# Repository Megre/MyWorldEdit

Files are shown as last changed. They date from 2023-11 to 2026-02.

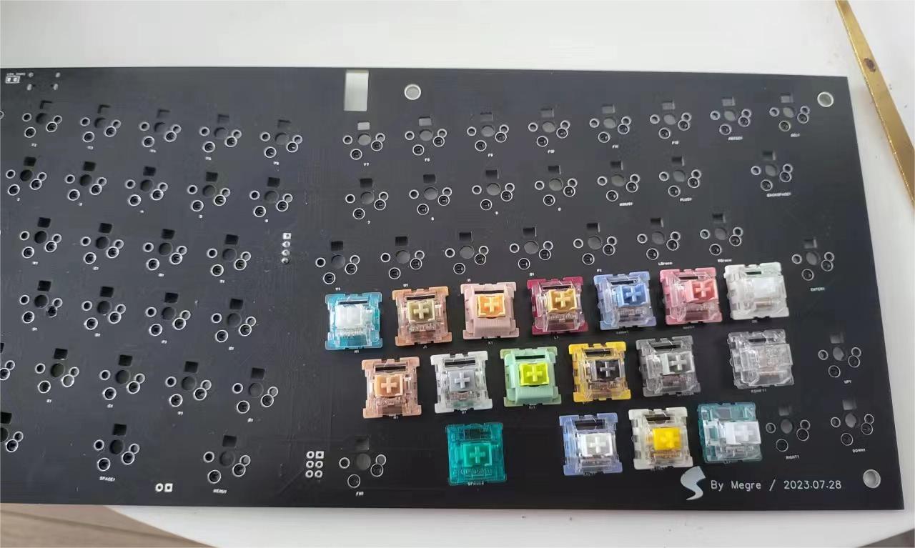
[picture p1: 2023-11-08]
Screenshots/微信图片_20231105111333.jpg

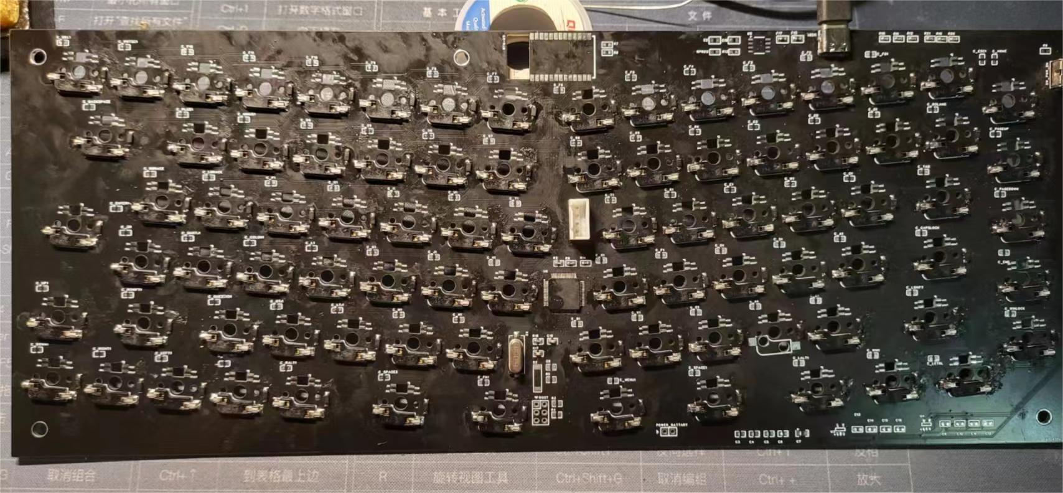
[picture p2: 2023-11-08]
Screenshots/微信图片_20231105111318.jpg

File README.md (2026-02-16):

# MyWorldEdit

Forked from: [WorldEdit](https://github.com/firestaradmin/WorldEdit-No.1)

微信图片_20231018185901

微信图片_20231105111314

## 主要特点

按照个人习惯，使用了欧式大回车。保留了PageUp、PageDown、Home、End、F01-12、方向键等，可用于程序编码及调试。空格使用了两个2.25u按键，实际使用感受正常，没有局促感。右Shift在大回车情况下保留了惯用位置，影响了方向键原有的“山”字布局，变为倒“L”。实际使用需要适应。主要特点：

- USB、蓝牙双模；

- 分裂布局， 欧式大回车；

- 高特青柠轴（五脚轴，支持热插拔）；
- 使用钢珠缩短了键程（1.5mm触发键程），声音小；
- RGB灯效。

与原项目的不同：

- 重新设计了键列，按键数、按键排布均不同；

- 去掉Logo等效，按键灯效改为RGB灯珠。键盘正常使用中，RGB驱动代码有待完善；

- 键盘尺寸不同，宽度约为普通笔记本键盘宽度（具体尺寸可查看外壳3D模型），主要考虑办公桌布局的紧凑。

## 外观

定位板粘贴的是梵高的《星夜》局部，手动裁剪镂空的（也可用喷绘贴纸，需要设计图纸给商家制作）。

上盖板是透明的。为了表现完整的图案，可采用透明键帽+按键文字喷绘粘贴。

图示键帽为Eva初号机。

## 内部结构

内部结构简易设计，从底向上依次为：

外壳，电路板，定位板，键轴，键帽，透明上盖板

- 外壳、定位板、透明上盖板均设计了3D模型。

- Eva初号机XDA键帽一套。由于使用了两个2.25u空格，这套键帽不够用。提供了2.25u键帽的3D模型，可自行打印（光固化打印细腻一些）。也可购买散装2.25u键帽（XDA，15元）。

- 简便起见外壳使用Eva图案和纸封边。

机械键盘素来讲求敲击手感和声音。这套简易设计，完全依靠电路板和定位板缓冲敲击，实际上也有一定的弹性（其他比较有名的结构如Gasket）。声音上，不求动听；反而在键轴内加入钢珠，缩短了键程（大概是选用轴的最短触发键程，实在受不了长键程的机械轴），追求输入简洁明快，有剪刀脚按键的直爽。

追求精致的可以自行设计，3D打印各种结构件进行喷涂、组装。

## BOM

BOM套个娃，参考原BOM，不同如下：

- [高特青柠轴V2](https://s.click.taobao.com/t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)（90颗75元）

- [凯华热插拔轴座](https://s.click.taobao.com/t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)（100个60元）

- [Eva初号机XDA键帽](https://s.click.taobao.com/t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)（35元）

- [蓝牙模块](https://item.taobao.com/item.htm?spm=a1z10.3-c.w4002-3762557689.9.30383217tBDbVX&id=543840346810)（XM-04-HID-K，26元。原BOM型号找不到，实测可用）

- [直径1.3mm钢珠](https://s.click.taobao.com/t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)（改键程用。每个键轴需要2个，用[开轴器](https://s.click.taobao.com/t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)开轴）

- [Eva初号机和纸](https://s.click.taobao.com/t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)（13元）

- 外壳可交商家3D打印（80元）

- 定位板为亚克力板（平面开洞，20元）

- 上盖板为PVC透明板（平面开洞，40元）

- 电路板嘉立创制作（5块板130元）

电子元件参考电路图（eprj文件）。

## 组合键

FN+

- F6: USB/Bluetooth mode
- F7: VolumeDown
- F8: VolumeUp
- F9: Mute
- F10: PlayORPause
- F11: Stop

Menu+

- ScrollLock: Logo LED switch
- Delete: Delete Connect Info
- Insert: Pair Mode
- Home: Bluetooth Reset
- End: Bluetooth Sleep
- F12: LED Flash
- F11: LED Breath
- F3: LED Mode3
- F2: LED Mode2, wasd
- F1: LED Mode1, all
- +: LED Brightness+
- -: LED Brightness-
- Esc: LED turn off

## DIY Tips

可参考[知乎上一篇帖子](https://zhuanlan.zhihu.com/p/116182565)，客制化关键步骤：

- [设计键盘配列](http://www.keyboard-layout-editor.com/)
- 使用该配列[生成定位板](http://builder.swillkb.com/)（DXF文件）
- PCB电路板设计
- 使用该配列[生成固件](https://kbfirmware.com/)（QMK固件），或自行编写固件

通俗的理解是，`键盘配列`给出了你想要的键盘布局，包括每个按键的位置，每个按键的尺寸等。

根据`键盘配列`生成的`DXF文件` 给出了每个键轴的放置位置，也就是`定位板`。由于键轴要穿过`定位板`的开孔插在PCB电路板上，设计PCB时也需要该`DXF文件`，因为定位板的开孔与PCB的`轴座`位置是一一对应的。

使用配列生成[QMK固件](https://qmk.fm/zh-cn/)的步骤不是必须的，也可以自行编写固件。[QMK](https://qmk.fm/zh-cn/)是一个开源项目，[支持STM32和若干非STM32主控](https://docs.qmk.fm/#/platformdev_selecting_arm_mcu)。使用工具自动生成QMK固件需要用到`键盘配列`，用于生成键盘行列的连接（主控识别按键通常基于行列扫描）。

### 键盘配列

设计你的按键排布。



设计输出可表示为文本形式的“Raw Data”，供后续步骤使用：

```
[{r:5,rx:8.75,ry:0.75,x:-7.25},"Esc","F1","F2","F3","F4","F5","F6"],
[{y:-0.5,x:-8.25},"Home"],
[{y:-0.5,x:-7.25},"~\n`","!\n1","@\n2","#\n3","$\n4","%\n5","^\n6"],
[{y:-0.5,x:-8.25},"Page\n\n\n\n\n\nUp"],
[{y:-0.5,x:-7.25,w:1.5},"Tab","Q","W","E","R","T"],
[{y:-0.5,x:-8.25},"Page\n\n\n\n\n\nDown"],
[{y:-0.5,x:-7.25,w:1.75},"Caps Lock","A","S","D","F","G"],
[{y:-0.5,x:-8.25},"End"],
[{y:-0.5,x:-7.25,w:2.25},"Shift","Z","X","C","V","B"],
[{y:-0.5,x:-8.25},"Win\n\n\n\n\n\nLock"],
[{y:-0.5,x:-7.25,w:1.25},"Ctrl",{w:1.25},"Win",{w:1.25},"Alt",{a:7,w:2.25},"",{a:4},"Menu"],
[{r:-5,rx:8.5,x:0.25},"F7","F8","F9","F10","F11","F12","PrtSc\nNmLk","Delete\nInsert"],
[{x:0.25},"&\n7","*\n8","(\n9",")\n0","_\n-","+\n=",{w:2},"Backspace"],
[{x:-0.25},"Y","U","I","O","P","{\n[","}\n]",{x:0.25,w:1.25,h:2,w2:1.5,h2:1,x2:-0.25},"Enter"],
["H","J","K","L",":\n;","\"\n'","|\n\\"],
[{x:0.5},"N","M","<\n,",">\n.","?\n/",{w:1.75},"Shift","↑"],
["Fn",{a:7,w:2.25},"",{a:4},"Alt","Ctrl","←","→","↓"]
```

### 定位板

这里使用的Switch Type是 `MX {_t: 1}`。不同Switch Type会影响开洞的尺寸和形状。



### PCB电路板

嘉立创还是不错的，找元件、设计、打板一体化（也有贴片和3D打印等服务）。

注意，从电路设计就要注意按键轴座的设计了。通常有支持热插拔和非热插拔两种。热插拔轴座需要贴在电路板上，会增加键盘的厚度。非热插拔方式，键轴直接焊接在电路板上。

**不同厂家的轴（如高特、佳达隆、凯华等）通常不兼容**，特别是矮轴等特殊轴，不仅轴插座不兼容，键帽也不兼容（有十字、猪鼻子等）。这就意味着，如果想使用某种轴，**定位板、PCB轴座，从设计之初就应该确定**，找好配套。

### 固件

行列的硬件连接如下图，与PCB设计对应。



基于原项目固件，按硬件连接做了对应改动。

在线配置生成QMK固件似乎也是可行方案。不建议新手使用这种方式。新手的主要问题是，各种细节的疏忽会导致DIY失败。围绕原项目或本项目进行微调，成功概率大。网络上公开的项目较多，但资源不完整，难以判断是否可用，难以学习和复现。至少这两个项目是证实可用的。

# HID Code

| Esc | F1 | F2 | F3 | F4 | F5 | F6 | F7 | F8 | F9 | F10 | F11 | F12 | PrtSc | ScrollLock | PauseBreak |
| --- | ----- | ---- | ----- | ----- | ---- | ---- | ----- | ---- | ----- | ----- | --- | ----- | --- | --- | --- |
| 0x29 | 0x3A  | 0x3B | 0x3C  | 0x3D  | 0x3E | 0x3F | 0x40  | 0x41 | 0x42  | 0x43  | 0x44 | 0x45  | 0x46 | 0x47 | 0x48 |
| | | | | | | | | | | | | | | | |
| ~ | ! | @ | # | $ | % | ^ | & | * | ( | ) | - | + | BackSpace | Insert | Home |
| 0x35 | 0x1E  | 0x1F | 0x20  | 0x21  | 0x22 | 0x23 | 0x24  | 0x25 | 0x26  | 0x27  | 0x2D | 0x2E  | 0x2A | 0x49 | 0x4A |
| | | | | | | | | | | | | | | | |
| Tab | Q | W | E | R | T | Y | U | I | O | P | { | } | \| | Delete | End |
| 0x2B | 0x14  | 0x1A | 0x08  | 0x15  | 0x17 | 0x1C | 0x18  | 0x0C | 0x12  | 0x13  | 0x2F | 0x30  | 0x31 | 0x4C | 0x4D |
| | | | | | | | | | | | | | | | |
| CapsLock | A | S | D | F | G | H | J | K | L | ; | ' | Enter | | | PageUp |
| 0x39 | 0x04  | 0x16 | 0x07  | 0x09  | 0x0A | 0x0B | 0x0D  | 0x0E | 0x0F  | 0x33  | 0x34 | 0x28  | 0x00 | 0x00 | 0x4B |
| | | | | | | | | | | | | | | | |
| LShift | Z | X | C | V | B | N | M | , | . | / | RShift | Up | | | PageDown |
| xxCK | 0x1D  | 0x1B | 0x06  | 0x19  | 0x05 | 0x11 | 0x10  | 0x36 | 0x37  | 0x38  | xxCK | 0x52  | 0x00 | 0x00 | 0x4E |
| | | | | | | | | | | | | | | | |
| LCtrl | Win | LAlt | Space | RAlt  | FN | Menu | RCtrl | Left | Down  | Right | | | | | |
| xxCK | xxCK  | xxCK | 0x2C  | xxCK  | xxSK | xxSK | xxCK  | 0x50 | 0x51  | 0x4F  | 0x00 | 0x00  | 0x00 | 0x00 | 0x00 |
| | | | | | | | | | | | | | | | |
| Sleep | LCtrl | Win  | LAlt  | Space | Menu | FN | Space | RAlt | RCtrl | Left  | Right  | Down  | | | |
| 0x82 | xxCK  | xxCK | xxCK  | 0x2C  | xxSK | xxSK | 0x2C  | xxCK | xxCK  | 0x50  | 0x4F | 0x51  | | | |

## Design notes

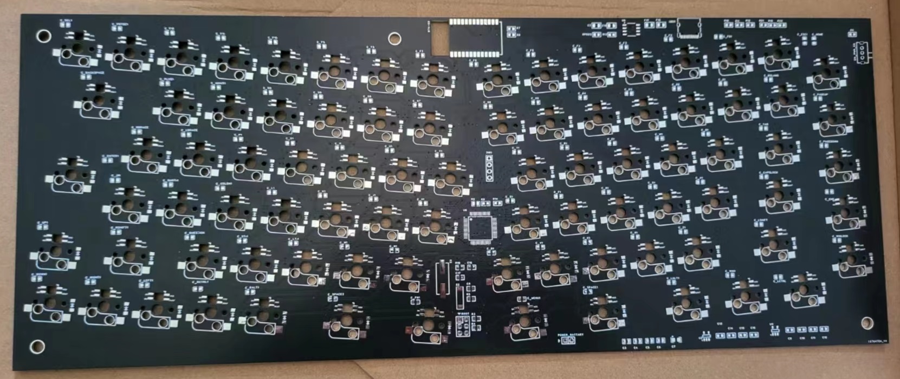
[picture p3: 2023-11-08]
Screenshots/微信图片_20231105111319.jpg

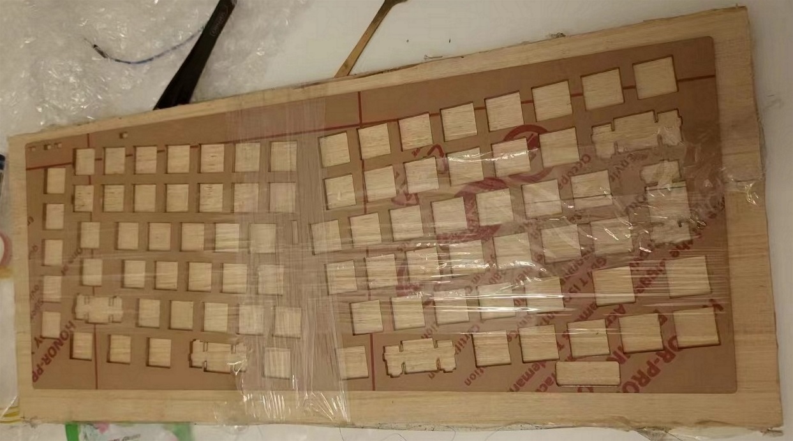
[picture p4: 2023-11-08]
Screenshots/微信图片_20231105111332.jpg

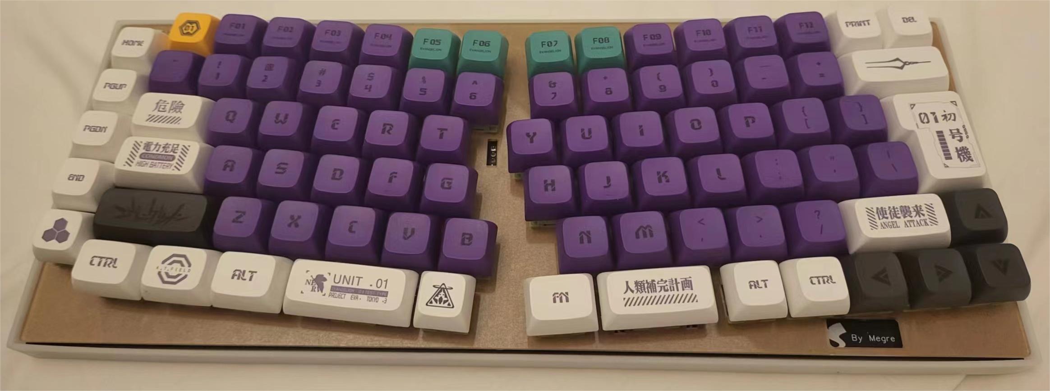
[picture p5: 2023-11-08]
Screenshots/微信图片_20231105111327.jpg

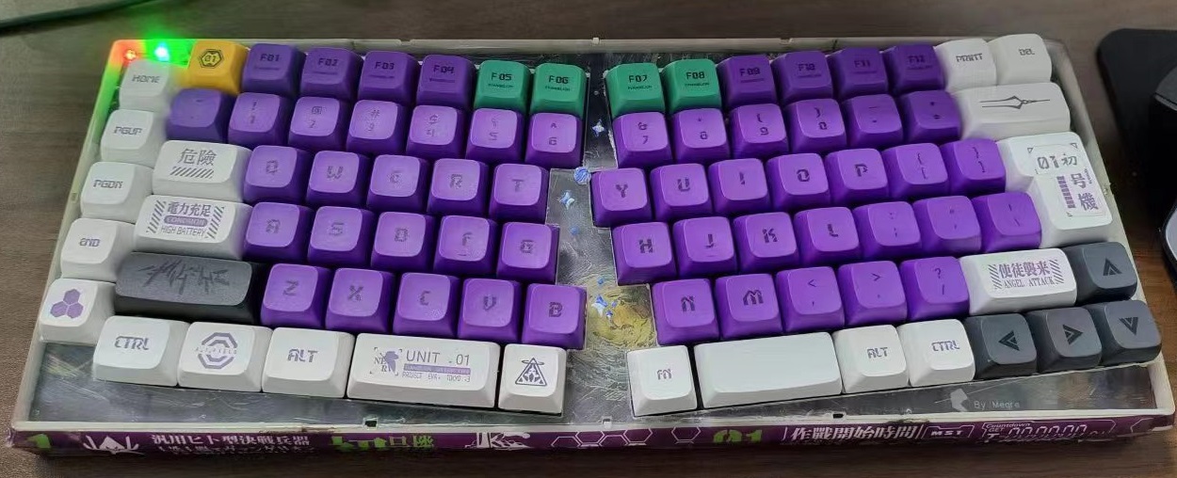
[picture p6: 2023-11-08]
Screenshots/微信图片_20231105111314.jpg

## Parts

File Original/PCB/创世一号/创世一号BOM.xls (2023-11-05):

Comment | Description | Designator | Footprint | LibRef | Quantity
HDR2x3 | Connector | BOOT | PIN-2x3-2.54-1.0 | HDR2x3 | 1
BTK-05-blueteeth |  | BTK-05 | BTK-05-bluteeth | BTK-05-blueteeth | 1
22pF | Capacitor | C1, C2 | RC0603 | CAP1 | 2
104 | Capacitor | C3, C4, C5, C6, C8 | RC0603 | CAP1 | 5
10uf | Tantalum Capacitor | C7 | CAP0805 | CAP-TANTALUM | 1
105 | Capacitor | C9, C12, C13, C16 | 0603 | CAP | 4
22nf | Capacitor | C10, C14 | 0603 | CAP | 2
104 | Capacitor | C11, C15 | 0603 | CAP | 2
10uf | Capacitor | C18, C19 | 0805 | CAP | 2
LED | LED | CAPS_LED, LED1, LED2, LED3, LED4, LED5, LED6, LED7, LED8, LED_CHRG, PWR, STATE_LED | LED-0805 | LED | 12
Diode |  | D2, D3, D4, D5, D6, D7, D8, D9, D10, D11, D12, D13, D14, D15, D16, D17, D18, D19, D20, D21, D22, D23, D24, D25, D26, D27, D28, D29, D30, D31, D32, D33, D34, D35, D36, D37, D38, D39, D40, D41, D42, D43, D44, D45, D46, D47, D48, D49, D50, D51, D52, D53, D54, D55, D56, D57, D58, D59, D60, D61, D62, D63, D64, D66, D67, D68, D69, D70, D71, D72, D73, D74, D75, D76, D77, D78, D82, D83, D84, D85, D86, D87, D88, D89, D90, D91, D92 | SDO-123 | Diode | 87
500mA | Resistor | F1 | 0805 | Res2 | 1
MX_SW | with Fixation pins 1-Pole w/LED | KEY_0, KEY_1, KEY_2, KEY_3, KEY_4, KEY_5, KEY_6, KEY_7, KEY_8, KEY_9, KEY_-, KEY_", KEY_/, KEY_;, KEY_[, KEY_\, KEY_], KEY_`, KEY_<, KEY_=, KEY_>, KEY_A, KEY_Alt, KEY_Alt2, KEY_B, KEY_Backspace, KEY_C, KEY_CapsLock, KEY_Ctrl, KEY_Ctrl2, KEY_D, KEY_Delete, KEY_Down, KEY_E, KEY_End, KEY_Enter, KEY_ESC, KEY_F, KEY_F1, KEY_F2, KEY_F3, KEY_F4, KEY_F5, KEY_F6, KEY_F7, KEY_F8, KEY_F9, KEY_F10, KEY_F11, KEY_F12, KEY_FN, KEY_G, KEY_H, KEY_Home, KEY_I, KEY_Insert, KEY_J, KEY_K, KEY_L, KEY_Left, KEY_M, KEY_Menu, KEY_N, KEY_O, KEY_P, KEY_PageDown, KEY_PageUp, KEY_Pause, KEY_PrtSc, KEY_Q, KEY_R, KEY_Right, KEY_S, KEY_ScrollLock, KEY_Shift, KEY_Shift2, KEY_Space, KEY_T, KEY_Tab, KEY_U, KEY_Up, KEY_V, KEY_W, KEY_Win, KEY_X, KEY_Y, KEY_Z | MX_SW-5 | MX_SW-5 | 87
HDR1x3 | Connector | LEDPwrCON | PIN-3-2.54-1.0 | HDR1x3 | 1
HDR1x2 | Connector | Power | PIN-2-2.54-1.0 | HDR1x2 | 1
NPN | NPN Bipolar Transistor | Q1 | S8050-TO-92 | NPN | 1
1M |  | R1 | RC0603 | R | 1
0R |  | R2 | RC0603 | R | 1
10K |  | R3, R4, R5 | RC0603 | R | 3
1k | Resistor, [NoValue] | R6, R7, R9, R13, R15, | 0603 | RES, R, Res2 | 5
1.5K | Resistor | R10 | 0603 | Res2 | 1
22R | Resistor | R11, R12,R17 | 0603 | Res2 | 3
10k | Resistor | R16 | 0603 | Res2 | 1
2k | Resistor | RPROG | 0603 | RES | 1
SW-SPST | Single-Pole, Single-Throw Switch | S1 | SMT-KEY | SW-SPST | 1
SWITCH-SPST | Switch | SW_PWR | Switch_3p_2.5mmjianju | SWITCH-SPST | 1
HDR1x4 | Connector | SWD | PIN-4-2.54-1.0 | HDR1x4 | 1
STM32F103RCT6 | MCU | U1 | QFP-64-0.5 | STM32F103RxTx | 1
HT16K33 SOP-28 |  | U2 | HT16K33-28PIN-SOP28 | HT16K33 SOP-28 | 1
RT9193 |  | U3, U4 | SOT-23-5 | RT9193 | 2
TP4056 |  | U5 | ESOP8 | TP4056 | 1
USB Slave_c | USB Connector | USB | MICRO USB CONNECTOR TYPEB-ST-MC-5F-01 | MICRO USB CONNECTOR TYPEB | 1
8M | Crystal Oscillator | X1 | HC49-SMD | XTAL_SMD | 1
名称 | 描述 | 封装 | 数量
HDR2x3 | Connector | PIN-2x3-2.54-1.0 | 1
BTK-05-blueteeth | 蓝牙HID模块 | BTK-05-bluteeth | 1
22pF | Capacitor | RC0603 | 2
104 | Capacitor | RC0603 | 5
10uf | Tantalum Capacitor | CAP0805 | 1
105 | Capacitor | 0603 | 4
22nf | Capacitor | 0603 | 2
104 | Capacitor | 0603 | 2
10uf | Capacitor | 0805 | 2
LED | LED | LED-0805 | 12
Diode | 二极管 | SDO-123 | 87
500mA | 限流保险管 | 0805 | 1
MX_SW | 键盘轴体 | MX_SW-5 | 87
HDR1x3 | Connector | PIN-3-2.54-1.0 | 1
HDR1x2 | Connector | PIN-2-2.54-1.0 | 1
NPN | NPN Bipolar Transistor | S8050-TO-92 | 1
1M |  | RC0603 | 1
0R |  | RC0603 | 1
10K |  | RC0603 | 3
1k | Resistor, [NoValue] | 0603 | 5
1.5K | Resistor | 0603 | 1
22R | Resistor | 0603 | 3
10k | Resistor | 0603 | 1
2k | Resistor | 0603 | 1
SW-SPST | 按键 | SMT-KEY | 1
SWITCH-SPST | 开关 | Switch_3p_2.5mmjianju | 1
HDR1x4 | Connector | PIN-4-2.54-1.0 | 1
STM32F103RCT6 | MCU主控 | QFP-64-0.5 | 1
HT16K33 SOP-28 | 灯控 | HT16K33-28PIN-SOP28 | 1
RT9193 | 稳压 | SOT-23-5 | 2
TP4056 | 电源管理 | ESOP8 | 1
USB Slave_c | MicroUSB母座 | MICRO USB CONNECTOR TYPEB-ST-MC-5F-01 | 1
8M | 晶振 | HC49-SMD | 1

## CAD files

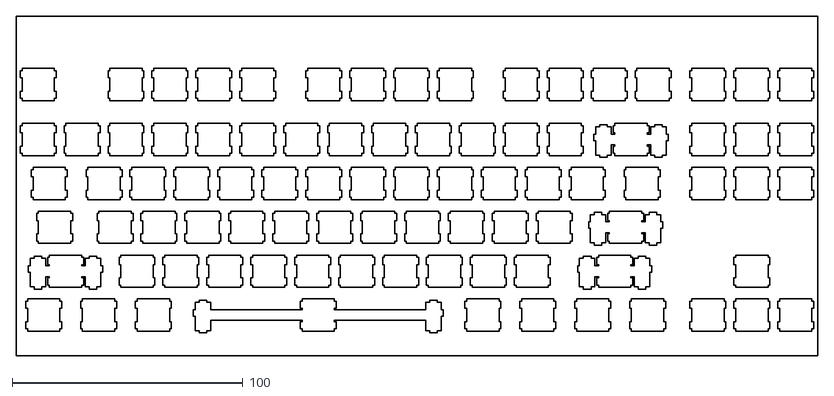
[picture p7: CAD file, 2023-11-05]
Original/LayOut/87layout.dxf
347.7 x 147.1

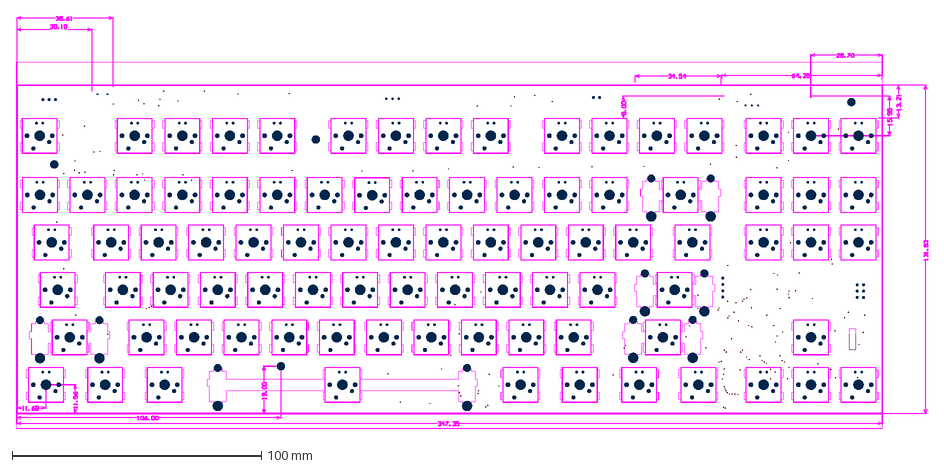
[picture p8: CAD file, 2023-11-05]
Original/PCB/创世一号/创世一号pcb.DXF
366.0 x 165.4 mm

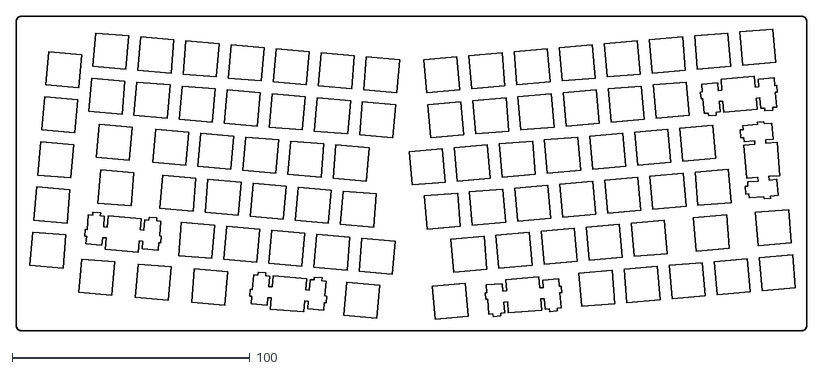
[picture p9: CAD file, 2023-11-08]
PCB/my plate case.dxf
332.5 x 132.2

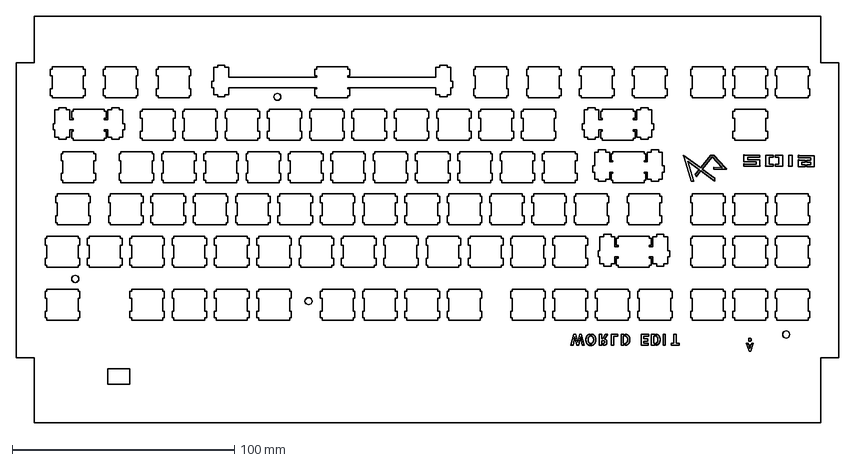
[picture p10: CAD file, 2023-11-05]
Original/SolidWorks外壳/平板型式 - 键盘钣金.DXF
370.1 x 183.2 mm

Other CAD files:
3D/2.25u.3dm
3D/上盖-亚克力.3dm
3D/上盖-内嵌.3dm
3D/上盖.3dm
3D/开关手柄.3dm

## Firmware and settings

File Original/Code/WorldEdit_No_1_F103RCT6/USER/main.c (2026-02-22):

#include "main.h"
#include "deepSleep.h"

void TIM3_CH3_PWM_init(u16 arr,u16 psc);
void myUSB_Init(void);
void sysInit(void);

static unsigned short sleepTime1SCounter = 0;
static uint32_t usbConfigStableTime = 0;
unsigned char sleepTime50MsCounter = 0;
unsigned char LED_breath_Flag = 0;
unsigned char LED_LOGOBreath_Flag = 0;
unsigned char LED_LOGOENBreath_Flag = 0;
unsigned char system_Status = 1;  	// 1:运行中，0：休眠中
unsigned char g_Flag = 0;
uint8_t ledLogoPWM = 80;
int8_t ledLogoPWMDelt = 0;
bool g_USBModeFlag = FALSE;
bool g_startUSBConfigStableTimer = FALSE;
static uint32_t g_sleepTimeout = 27; // 秒

int main()
{
	sysInit();	
	BTK05_Wake();	
	Turn_On_State_LEDs(1);

	while(1)
	{ 
		if(g_USBModeFlag) //USB模式下 
		{
			if(sleepTime1SCounter <= 1000)
			{
				myKeyBoard_ScanKeyAndUpdataATBuffer();//键盘事件更新
				if(g_myKeyBoard_DataWaitForUploadFlag == 1)
				{
					sleepTime1SCounter = 0;
					g_myKeyBoard_DataWaitForUploadFlag = 0;
					if(bDeviceState == CONFIGURED)//如果连接上了 USB
						Keyboard_Send(BTK05_ATKeyDataPack+4);
					//GPIO_SetBits(LED_LOGO_GPIOPort,LED_LOGO_GPIOPin);
				}
				
				Try_Switch_to_BLUETEETH_Mode();
				continue;
			}
			
			if(system_Status == 0)
			{
				myKeyBoard_ScanKeyAndUpdataATBuffer();//键盘事件更新
				if(g_myKeyBoard_DataWaitForUploadFlag == 1)
				{
					g_myKeyBoard_DataWaitForUploadFlag = 0;
					if(bDeviceState == CONFIGURED)//如果连接上了 USB
						Keyboard_Send(BTK05_ATKeyDataPack+4);
					//GPIO_SetBits(LED_LOGO_GPIOPort,LED_LOGO_GPIOPin);
					system_Status = 1;
					TIM_Cmd(TIM2, ENABLE);  //使能TIMx	
					sleepTime1SCounter = 0;
					if(LED_Status)	
						LED_WakeUp();	
				}
				continue;
			}
			
			if(sleepTime1SCounter > 1000)
			{
				TIM_Cmd(TIM2, DISABLE);  //失能TIMx		
				system_Status = 0;
				LED_GoToSleep();
			}
		}
		else//蓝牙模块模式
		{
			// 一段时间后没有按下任何按键，则进入休眠状态
			if(sleepTime1SCounter >= g_sleepTimeout && BTK05_Status == BTK_WAKE)   
			{				
				//进入休眠模式...
				BTK05_Sleep();           // 休眠BTK05
				TIM_Cmd(TIM2, DISABLE);  // 失能TIMx		
				system_Status = 0;
				LED_ESCOFF();	 
				
				// 让 MCU 休眠, 进入STOP模式
				Enter_Deep_Sleep();	  
    
				// 唤醒后执行
				BTK05_Wake();
				TIM_Cmd(TIM2, ENABLE);
				system_Status = 1;  		// 恢复工作状态
				sleepTime1SCounter = 0; // 清除休眠计时
			}
			//如果键盘处于醒着的状态
			else if(sleepTime1SCounter < g_sleepTimeout && BTK05_Status == BTK_WAKE)
			{
				myKeyBoard_ScanKeyAndUpdataATBuffer();//键盘事件更新
				if(g_myKeyBoard_DataWaitForUploadFlag == 1)
				{
					g_myKeyBoard_DataWaitForUploadFlag = 0;
					//GPIO_ResetBits(LED_LOGO_GPIOPort,LED_LOGO_GPIOPin);
					BTK05_UART_SendKeyData(BTK05_ATKeyDataPack,12);
					sleepTime1SCounter = 0;

//					if(ATKeyControlByte5 != 0) 
//					{
//						GPIO_SetBits(LED_LOGO_GPIOPort,LED_LOGO_GPIOPin);
//					}
//					else
//					{
//						GPIO_ResetBits(LED_LOGO_GPIOPort,LED_LOGO_GPIOPin);
//					}
				}
			}
			//如果蓝牙处于休眠状态
			else if(BTK05_Status == BTK_SLEEP)
			{
				myKeyBoard_ScanKeyAndUpdataATBuffer();
				if(g_myKeyBoard_DataWaitForUploadFlag == 1)
				{
					system_Status = 1;
					BTK05_Wake();//唤醒BTK05
					TIM_Cmd(TIM2, ENABLE);  //使能TIMx	
					sleepTime1SCounter = 0;
					g_myKeyBoard_DataWaitForUploadFlag = 0;
					if(LED_Status)	
						LED_WakeUp();
					BTK05_UART_SendKeyData(BTK05_ATKeyDataPack,12);
				}
			}
			
			Try_Switch_to_USB_Mode();
			
		}
		
//		if(LED_BreathEfectFlag && LED_breath_Flag)
//		{
//			LED_BreathProcess();
//			LED_breath_Flag = 0;
//		}
//		if(LED_LOGOBreath_Flag  && LED_LOGOENBreath_Flag)//logo呼吸灯处理标志
//		{
//			TIM_SetCompare3(TIM3, ledLogoPWM);
//			if(ledLogoPWMDelt == 0)
//			{
//				ledLogoPWM --;
//				if(ledLogoPWM <= 30)
//					ledLogoPWMDelt = 1;
//			}
//			else
//			{
//				ledLogoPWM ++;
//				if(ledLogoPWM == 98)
//					ledLogoPWMDelt = 0;
//			}
//			LED_LOGOBreath_Flag = 0;

//		}
	}
}

// megre
void Try_Switch_to_USB_Mode(void)
{
	if(bDeviceState == CONFIGURED) { //如果连接上了 USB
		if(!g_startUSBConfigStableTimer) {
			usbConfigStableTime = 0;
			g_startUSBConfigStableTimer = TRUE;
		}
		else if(usbConfigStableTime >= 500) {					
			USB_Mode();
			g_startUSBConfigStableTimer = FALSE;
		}
	}
	else {
		 g_startUSBConfigStableTimer = FALSE;
		 usbConfigStableTime = 0;
	}
}

void Try_Switch_to_BLUETEETH_Mode(void)
{
	if(bDeviceState != CONFIGURED) { //如果没连上 USB
		if(!g_startUSBConfigStableTimer) {
			usbConfigStableTime = 0;
			g_startUSBConfigStableTimer = TRUE;
		}
		else if(usbConfigStableTime >= 500) {					
			BLUETEETH_Mode();
			g_startUSBConfigStableTimer = FALSE;
		}
	}
	else {
		 g_startUSBConfigStableTimer = FALSE;
		 usbConfigStableTime = 0;
	}
}


//定时器中断服务程序
void TIM2_IRQHandler(void)   //TIM中断
{
	if (TIM_GetITStatus(TIM2, TIM_IT_Update) != RESET)  //检查TIM更新中断发生与否
		{
			TIM_ClearITPendingBit(TIM2, TIM_IT_Update  );  //清除TIMx更新中断标志 
				
			sleepTime50MsCounter++;
			LED_LOGOBreath_Flag = 1;
			
			if(sleepTime50MsCounter % 4 == 0)
				LED_breath_Flag = 1;							

			if(g_startUSBConfigStableTimer) {
				usbConfigStableTime += 50;
			}
			
			if(sleepTime50MsCounter == 20)	
			{				
				sleepTime50MsCounter = 0;                   
				sleepTime1SCounter++;				
			}
			
			//LED_breath_Timer50ms++;	
		}
}


void sysInit()
{
	GPIO_DeInit(GPIOA);
	GPIO_DeInit(GPIOB);
	GPIO_DeInit(GPIOC);
	RCC_APB2PeriphClockCmd(RCC_APB2Periph_GPIOA,ENABLE);
	RCC_APB2PeriphClockCmd(RCC_APB2Periph_GPIOB,ENABLE);
	RCC_APB2PeriphClockCmd(RCC_APB2Periph_GPIOC,ENABLE);
	NVIC_PriorityGroupConfig(NVIC_PriorityGroup_2);
	DelayInit();	
	
	myKeyBoard_GPIO_Init();	
	
	BTK05_Init();	
	
	LED_LOGO_GPIO_Init();
	LED_I2C_Configuration();
	LED_HT16K33_Init();//初始化芯片
	
	//TIM3_CH3_PWM_init(100,0);
	TIM2_Int_Init(1000,3600);//50ms一次中断
	myUSB_Init();
}

//通用定时器2中断初始化
//这里时钟选择为APB1的2倍，而APB1为36M
//arr：自动重装值。
//psc：时钟预分频数
//一次中断的时间为t：t = (arr * psc / APB1*2) * 1000 ms
void TIM2_Int_Init(u16 arr,u16 psc)
{
    TIM_TimeBaseInitTypeDef  TIM_TimeBaseStructure;
	NVIC_InitTypeDef NVIC_InitStructure;
 
	RCC_APB1PeriphClockCmd(RCC_APB1Periph_TIM2, ENABLE); //时钟使能
	
	//定时器TIM3初始化
	TIM_TimeBaseStructure.TIM_Period = arr; //设置在下一个更新事件装入活动的自动重装载寄存器周期的值	
	TIM_TimeBaseStructure.TIM_Prescaler =psc; //设置用来作为TIMx时钟频率除数的预分频值
	TIM_TimeBaseStructure.TIM_ClockDivision = TIM_CKD_DIV1; //设置时钟分割:TDTS = Tck_tim
	TIM_TimeBaseStructure.TIM_CounterMode = TIM_CounterMode_Up;  //TIM向上计数模式
	TIM_TimeBaseInit(TIM2, &TIM_TimeBaseStructure); //根据指定的参数初始化TIMx的时间基数单位
 
	TIM_ITConfig(TIM2,TIM_IT_Update,ENABLE ); //使能指定的TIM中断,允许更新中断
 
	//中断优先级NVIC设置
	NVIC_InitStructure.NVIC_IRQChannel = TIM2_IRQn;  //TIM中断
	NVIC_InitStructure.NVIC_IRQChannelPreemptionPriority = 0;  //先占优先级级
	NVIC_InitStructure.NVIC_IRQChannelSubPriority = 2;  //从优先级级
	NVIC_InitStructure.NVIC_IRQChannelCmd = ENABLE; //IRQ通道被使能
	NVIC_Init(&NVIC_InitStructure);  //初始化NVIC寄存器

	TIM_Cmd(TIM2, ENABLE);  //使能TIMx					 
}


void USB_Mode(void)
{
	g_USBModeFlag = TRUE;	
	
	//BTK05进入休眠模式...
	BTK05_Sleep();//休眠BTK05
	sleepTime1SCounter = 0;
	TIM_Cmd(TIM2, ENABLE);  		
	//system_Status = 1;
	//LED_GoToSleep();
	//GPIO_SetBits(LED_LOGO_GPIOPort,LED_LOGO_GPIOPin);
}

void BLUETEETH_Mode(void)
{
	g_USBModeFlag = FALSE;	
	
	BTK05_Wake();//唤醒BTK05
	TIM_Cmd(TIM2, ENABLE);  //使能TIMx	
	sleepTime1SCounter = 0;
	//GPIO_ResetBits(LED_LOGO_GPIOPort,LED_LOGO_GPIOPin);
}


void myUSB_Init(void)
{
	USB_Port_Set(1);	//开启USB连接
	//USB配置
 	USB_Interrupts_Config();    
 	Set_USBClock();   
 	USB_Init();	 
}


void TIM3_CH3_PWM_init(u16 arr,u16 psc)
{
    //配置TIM3
    TIM_TimeBaseInitTypeDef TIM_TimeBaseStructure;//注意结构体的声明必须在函数的开头
    TIM_OCInitTypeDef TIM_OCInitStructure;
    GPIO_InitTypeDef GPIO_InitStructure;

    RCC_APB1PeriphClockCmd(RCC_APB1Periph_TIM3,ENABLE);
    TIM_TimeBaseStructure.TIM_ClockDivision=TIM_CKD_DIV1;
    TIM_TimeBaseStructure.TIM_CounterMode=TIM_CounterMode_Up;
    TIM_TimeBaseStructure.TIM_Period=arr;
    TIM_TimeBaseStructure.TIM_Prescaler=psc;
    TIM_TimeBaseInit(TIM3,&TIM_TimeBaseStructure);

    //配置TIM3 Channel3 PWM

    TIM_OCInitStructure.TIM_OCMode=TIM_OCMode_PWM2;
    TIM_OCInitStructure.TIM_OCPolarity=TIM_OCPolarity_High;
    TIM_OCInitStructure.TIM_OutputState=TIM_OutputState_Enable;
    TIM_OC3Init(TIM3,&TIM_OCInitStructure);//注意此处的函数名字以及函数的入口参数

    //配置GPIO口，并且设置成复用功能

    RCC_APB2PeriphClockCmd(RCC_APB2Periph_GPIOB,ENABLE);
//    RCC_APB2PeriphClockCmd(RCC_APB2Periph_AFIO,ENABLE);
    GPIO_InitStructure.GPIO_Mode=GPIO_Mode_AF_PP;
    GPIO_InitStructure.GPIO_Pin=GPIO_Pin_0;
    GPIO_InitStructure.GPIO_Speed=GPIO_Speed_50MHz;
    GPIO_Init(GPIOB,&GPIO_InitStructure);
	GPIO_ResetBits(GPIOB,GPIO_Pin_0);
    //把TIM3部分重映射到PB5
    //GPIO_PinRemapConfig(GPIO_PartialRemap_TIM3,ENABLE);

    //使能TIM3时钟
    TIM_Cmd(TIM3,DISABLE);
}

//void LED_LOGO_FLASH_3TIMES()
//{
//	
////------------------------------------------------------
//	

//}

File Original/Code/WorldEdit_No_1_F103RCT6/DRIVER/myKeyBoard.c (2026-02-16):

#include "main.h"
#include "myKeyBoard.h"
#include <string.h>

#define myKeyBoard_ControlKey 0x00
#define myKeyBoard_SpecialKey 0x00

#define xxCK	myKeyBoard_ControlKey 
#define xxSK	myKeyBoard_SpecialKey 

#define MENU_STATE 	myKeyBoard_KeyState[5][5]
#define FN_STATE 		myKeyBoard_KeyState[5][6]

const char * myKeyBoard_KeyMap_Name[6][16] = 
{
	"Esc","F1","F2","F3","F4","F5","F6","F7","F8","F9","F10","F11","F12","PrtSc","Delete","",
	"Home","~","!","@","#","$","%","^","&","*","(",")","-","+","BackSpace","",
	"PageUp","Tab","Q","W","E","R","T","Y","U","I","O","P","{","}","Enter","",
	"PageDown","CapsLock","A","S","D","F","G","H","J","K","L",";","'","|","","",
	"End","LShift","Z","X","C","V","B","N","M",",",".","/","RShift","Up","","",
	"Sleep","LCtrl","Win","LAlt","Space","Menu","FN","Space","RAlt","RCtrl","Left","Right","Down","","",""
};


const unsigned char myKeyBoard_KeyMap_ATValue[6][16] = 
{
	0x29,0x3A,0x3B,0x3C,0x3D,0x3E,0x3F,0x40,0x41,0x42,0x43,0x44,0x45,0x46,0x4C,0x00,
	0x4A,0x35,0x1E,0x1F,0x20,0x21,0x22,0x23,0x24,0x25,0x26,0x27,0x2D,0x2E,0x2A,0x00,
	0x4B,0x2B,0x14,0x1A,0x08,0x15,0x17,0x1C,0x18,0x0C,0x12,0x13,0x2F,0x30,0x28,0x00,
	0x4E,0x39,0x04,0x16,0x07,0x09,0x0A,0x0B,0x0D,0x0E,0x0F,0x33,0x34,0x31,0x00,0x00,
	0x4D,xxCK,0x1D,0x1B,0x06,0x19,0x05,0x11,0x10,0x36,0x37,0x38,xxCK,0x52,0x00,0x00,
	0x82,xxCK,xxCK,xxCK,0x2C,xxSK,xxSK,0x2C,xxCK,xxCK,0x50,0x4F,0x51,0x00,0x00,0x00
};


//const unsigned char myKeyBoard_KeyMap_ATValue[6][16] = 
//{
//	0x29,0x3A,0x3B,0x3C,0x3D,0x3E,0x3F,0x40,0x41,0x42,0x43,0x44,0x45,0x46,0x47,0x48,
//	0x35,0x1E,0x1F,0x20,0x21,0x22,0x23,0x24,0x25,0x26,0x27,0x2D,0x2E,0x2A,0x49,0x4A,
//	0x2B,0x14,0x1A,0x08,0x15,0x17,0x1C,0x18,0x0C,0x12,0x13,0x2F,0x30,0x31,0x4C,0x4D,
//	0x39,0x04,0x16,0x07,0x09,0x0A,0x0B,0x0D,0x0E,0x0F,0x33,0x34,0x28,0x00,0x00,0x4B,
//	0xE1,0x1D,0x1B,0x06,0x19,0x05,0x11,0x10,0x36,0x37,0x38,0xE5,0x52,0x00,0x00,0x4E,
//	0xE0,0xE3,0xE2,0x2C,0xE6,0x00,0x76,0xE4,0x50,0x51,0x4F,0x00,0x00,0x00,0x00,0x00,
//};

const uint16_t key_Col_Pin[16] = 
{
	myKeyBoard_col0_GPIOPin,
	myKeyBoard_col1_GPIOPin,
	myKeyBoard_col2_GPIOPin,	
	myKeyBoard_col3_GPIOPin,	
	myKeyBoard_col4_GPIOPin,	
	myKeyBoard_col5_GPIOPin,	
	myKeyBoard_col6_GPIOPin,	
	myKeyBoard_col7_GPIOPin,	
	myKeyBoard_col8_GPIOPin,	
	myKeyBoard_col9_GPIOPin,	
	myKeyBoard_col10_GPIOPin,	
	myKeyBoard_col11_GPIOPin,	
	myKeyBoard_col12_GPIOPin,	
	myKeyBoard_col13_GPIOPin,	
	myKeyBoard_col14_GPIOPin,	
	myKeyBoard_col15_GPIOPin	
		
};

typedef struct 
{
	unsigned char ATKeyData;
	unsigned char rowN;
	unsigned char colN;
}ATKeyDataStructureTypedef;

//普通按键暂存数组
ATKeyDataStructureTypedef ATKeyData[6];
unsigned char ATKeyControlByte5 = 0x00;//状态控制键字节 如Shift Ctrl键等
//6行x16列键盘 状态数组
KeyState_enumTypedef myKeyBoard_KeyState[6][16] = {KEYUNPRESSED};//当前按键状态
KeyState_enumTypedef myKeyBoard_KeyState_Ex[6][16] = {KEYUNPRESSED};//上次按键状态

u8 LOGO_LED_Status = 0;

unsigned char myKeyBoard_KeyStateChangedFlag = 0;//键盘状态改变标志
unsigned char myKeyBoard_KeyIsControl = 1;//键盘控制按键标志
unsigned char g_myKeyBoard_DataWaitForUploadFlag = 0;//数据等待上传标志

void myKeyBoard_ControlKeyProcess(u8 rowi, u8 colj);
void myKeyBoard_KeyScan_rowScan(GPIO_TypeDef *col_GPIOPort, 
								uint8_t col_GPIOPin_Index, const uint16_t *p_col_GPIOPin);

// megre
void clear_keyboard_state(void)
{
		g_myKeyBoard_DataWaitForUploadFlag = 0;
		for (int i = 0; i < 6; i++) {
        for (int j = 0; j < 16; j++) {
            myKeyBoard_KeyState[i][j] = KEYUNPRESSED;
            myKeyBoard_KeyState_Ex[i][j] = KEYUNPRESSED;
        }
    }
}

//键盘更新
void myKeyBoard_ScanKeyAndUpdataATBuffer()
{
	myKeyBoard_KeyScan();//物理层键盘状态扫描，按键是否被按下 ， 
	myKeyBoard_JudgeKeyStateChange();//判断键盘状态是否有变化，有则置位myKeyBoard_KeyStateChangedFlag标志
	
	if(myKeyBoard_KeyStateChangedFlag)//判断是否有变化
	{
		myKeyBoard_KeyStateChangedFlag = 0;
		myKeyBoard_UpdataATDataPack();//键盘AT数据包更新
		g_myKeyBoard_DataWaitForUploadFlag = 1;//置位数据等待上传标志
	}
}

/*
*/


//定义 FN组合键的枚举，方便下面键值处理
enum{
	none = 0,
	Mute = 1,
	VolumeUp = 2,
	VolumeDown = 3,
	PlayORPause = 4,
	Stop = 5
}	specialKeyenum = none;

void ConsumerKeyProcess(void)//处理FN组合功能键，并发送给BTK05
{
	BTK05_ConsumerPack[5] = 0x00;//清零
	switch(specialKeyenum)
	{
		case Mute:
			//specialATKeyValueTemp = 0x7F;
			BTK05_ConsumerPack[5] |= (0x01 << 0); 
			break;
		case VolumeUp:
			BTK05_ConsumerPack[5] |= (0x01 << 2);
			break;
		case VolumeDown:
			BTK05_ConsumerPack[5] |= (0x01 << 1);
			break;
		case PlayORPause:
			BTK05_ConsumerPack[5] |= (0x01 << 3);
			break;
		case Stop:
			BTK05_ConsumerPack[5] |= (0x01 << 4);
			break;
		default:
			break;
	}
	
	BTK05_UART_SendKeyData(BTK05_ConsumerPack,8);
	BTK05_ConsumerPack[5] = 0x00;//清零
	BTK05_UART_SendKeyData(BTK05_ConsumerPack,8);
}
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

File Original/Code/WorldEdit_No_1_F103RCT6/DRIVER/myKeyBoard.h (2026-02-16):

#ifndef __MYKEYBOARD_H_
#define __MYKEYBOARD_H_
//#include "main.h"

#define myKeyBoard_row_GPIOPort		GPIOA
#define myKeyBoard_row0_GPIOPin		GPIO_Pin_0
#define myKeyBoard_row1_GPIOPin		GPIO_Pin_1
#define myKeyBoard_row2_GPIOPin		GPIO_Pin_2
#define myKeyBoard_row3_GPIOPin		GPIO_Pin_3
#define myKeyBoard_row4_GPIOPin		GPIO_Pin_4
#define myKeyBoard_row5_GPIOPin		GPIO_Pin_5

#define myKeyBoard_col3_0_GPIOPort	GPIOB
#define myKeyBoard_col0_GPIOPort	GPIOB
#define myKeyBoard_col1_GPIOPort	GPIOB
#define myKeyBoard_col2_GPIOPort	GPIOB
#define myKeyBoard_col3_GPIOPort	GPIOB
#define myKeyBoard_col15_4_GPIOPort	GPIOC
#define myKeyBoard_col4_GPIOPort	GPIOC
#define myKeyBoard_col5_GPIOPort	GPIOC
#define myKeyBoard_col6_GPIOPort	GPIOC
#define myKeyBoard_col7_GPIOPort	GPIOC
#define myKeyBoard_col8_GPIOPort	GPIOC
#define myKeyBoard_col9_GPIOPort	GPIOC
#define myKeyBoard_col10_GPIOPort	GPIOC
#define myKeyBoard_col11_GPIOPort	GPIOC
#define myKeyBoard_col12_GPIOPort	GPIOC
#define myKeyBoard_col13_GPIOPort	GPIOC
#define myKeyBoard_col14_GPIOPort	GPIOC
#define myKeyBoard_col15_GPIOPort	GPIOC

#define myKeyBoard_col0_GPIOPin		GPIO_Pin_12
#define myKeyBoard_col1_GPIOPin		GPIO_Pin_13
#define myKeyBoard_col2_GPIOPin		GPIO_Pin_14
#define myKeyBoard_col3_GPIOPin		GPIO_Pin_15
#define myKeyBoard_col4_GPIOPin		GPIO_Pin_6
#define myKeyBoard_col5_GPIOPin		GPIO_Pin_7
#define myKeyBoard_col6_GPIOPin		GPIO_Pin_8
#define myKeyBoard_col7_GPIOPin		GPIO_Pin_9
#define myKeyBoard_col8_GPIOPin		GPIO_Pin_4
#define myKeyBoard_col9_GPIOPin		GPIO_Pin_5
#define myKeyBoard_col10_GPIOPin	GPIO_Pin_10
#define myKeyBoard_col11_GPIOPin	GPIO_Pin_0
#define myKeyBoard_col12_GPIOPin	GPIO_Pin_1
#define myKeyBoard_col13_GPIOPin	GPIO_Pin_2
#define myKeyBoard_col14_GPIOPin	GPIO_Pin_3
#define myKeyBoard_col15_GPIOPin	GPIO_Pin_11


typedef enum 
{
	KEYUNPRESSED= 0,
	KEYPRESSED  = ~KEYUNPRESSED
}KeyState_enumTypedef;

//extern KeyState_enumTypedef myKeyBoard_KeyState[6][16];
extern unsigned char g_myKeyBoard_DataWaitForUploadFlag;//数据等待上传标志
extern unsigned char ATKeyControlByte5 ;//状态控制键字节 如Shift Ctrl键等


void myKeyBoard_GPIO_Init(void);//按键IO初始化
void myKeyBoard_KeyScan(void);//物理层键盘状态扫描，按键是否被按下 

void myKeyBoard_JudgeKeyStateChange(void);//判断键盘状态是否有变化，有则置位myKeyBoard_KeyStateChangedFlag标志
void myKeyBoard_UpdataATDataPack(void);//键盘AT数据包更新
void myKeyBoard_ScanKeyAndUpdataATBuffer(void);//键盘扫描并更新Key数据包
unsigned char myKeyBoard_JudgeKeyPressWithName(const char* keyName);
void myKeyBoard_Process_All(void);//键盘中心程序
void clear_keyboard_state(void);
#endif

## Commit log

2023-11-05 organize folder
    [87layout.dxf, KeyBoard.PcbLib, KeyBoard.SchLib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]
2023-11-08 Screenshots, 3D models and PCB
    [2.25u.3dm, 2.25u.SLDPRT, 2.25u空格.SLDPRT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]
2026-02-16 add：deep sleep of MCU
2026-02-17 空格唤醒改为Menu唤醒
2026-02-19 任意键唤醒
2026-02-22 临时使用RGB1控制状态指示LED在唤醒/睡眠时的通断（灯效仍未实现）
